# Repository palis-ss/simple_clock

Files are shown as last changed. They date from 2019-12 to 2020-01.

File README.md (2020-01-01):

# simple_clock

## Description
This repository contains the firmware for a replacement clock that I put into an old chassis.  The old clock was an analog clock.  I rebuilt a new one as a digital clock using 7-segment LEDs.  It uses the Blue Pill board ([Link](https://stm32-base.org/boards/STM32F103C8T6-Blue-Pill)) as its processor and relies on the RTC module of the STM32.  I removed the battery and replaced with a DC jack.  I also added a backup battery for the RTC.

The replacement clock must fit in the old chassis, so I made a bracket with 3D printing.  The mainboard that holds the Blue Pill and the 7-segments was designed in Eagle, which the schematics and gerber files are included in this repo.

For the firmware, the project was created using STM32CubeMX which uses STM32 HAL as the library.  The code is actually simple but I made it look harder than it actually is.  The big chunk of code is how I handle buttons.  The part about time keeping is not so much as the RTC on this MCU is very easy to use.  Nonetheless, there are a number of problems with the HAL library.  I'm listing the ones that affected this project here.
- The RTC's `HAL_RTC_GetTime` must be followed by the `HAL_RTC_GetDate` in order for it to work properly.
- The initialization routine `MX_RTC_Init`, by default, intializes the RTC's time to 0.  This part must be removed manually in order to use backup time from RTC.
- The default IRQ handler for Systick Interrupt is not called in the interrupt routine.  You must add it manually.  This part is a minor problem and not relevant to this project but I use it so I decided to mention here anyway.

## Notes on Board Assembling
- Make sure to take care of vias first if you develop the board yourself.
- Then do the MAX7219 next as it needs to be soldered on both sides.
- The rest of components can be soldered anytime afterwards.

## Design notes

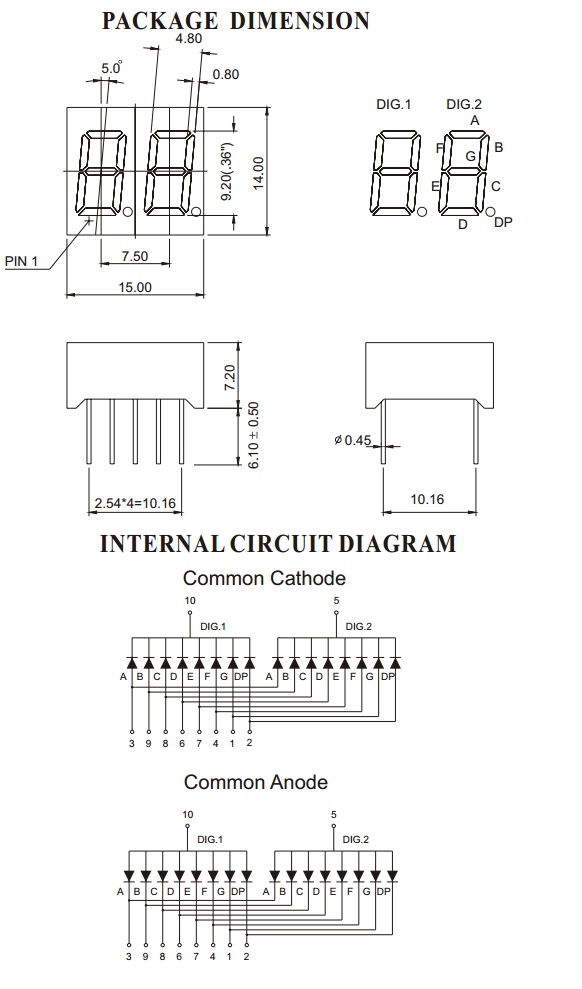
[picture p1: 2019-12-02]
ref/8z.jpg

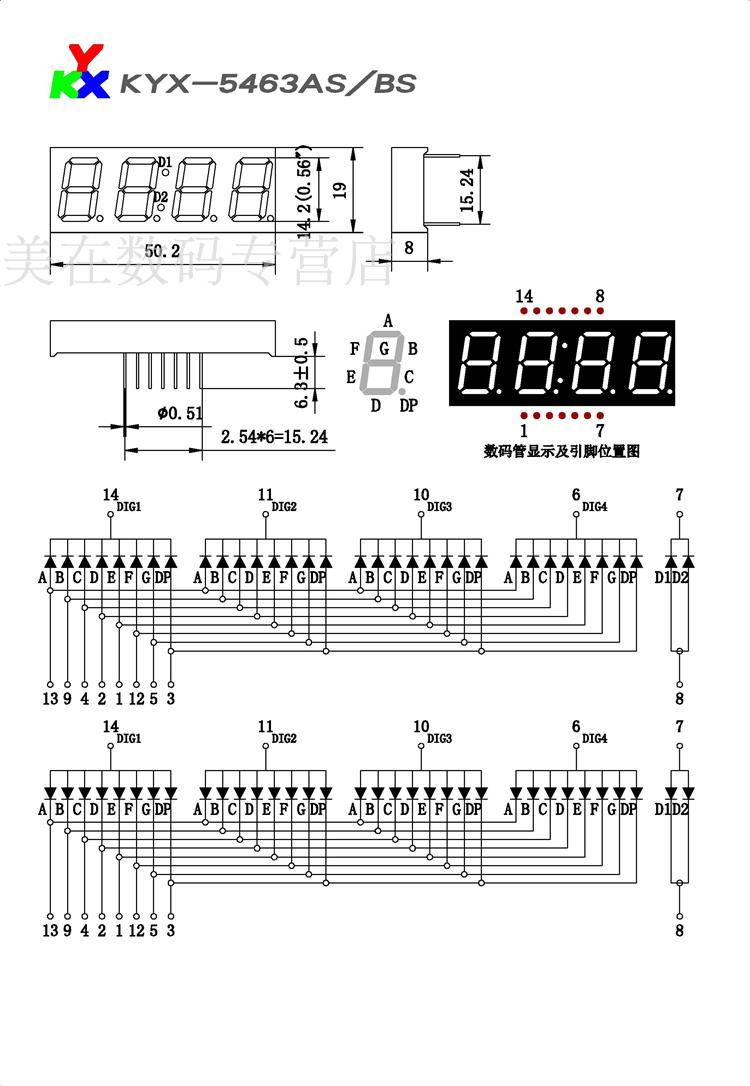
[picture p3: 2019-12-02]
ref/yp.jpg

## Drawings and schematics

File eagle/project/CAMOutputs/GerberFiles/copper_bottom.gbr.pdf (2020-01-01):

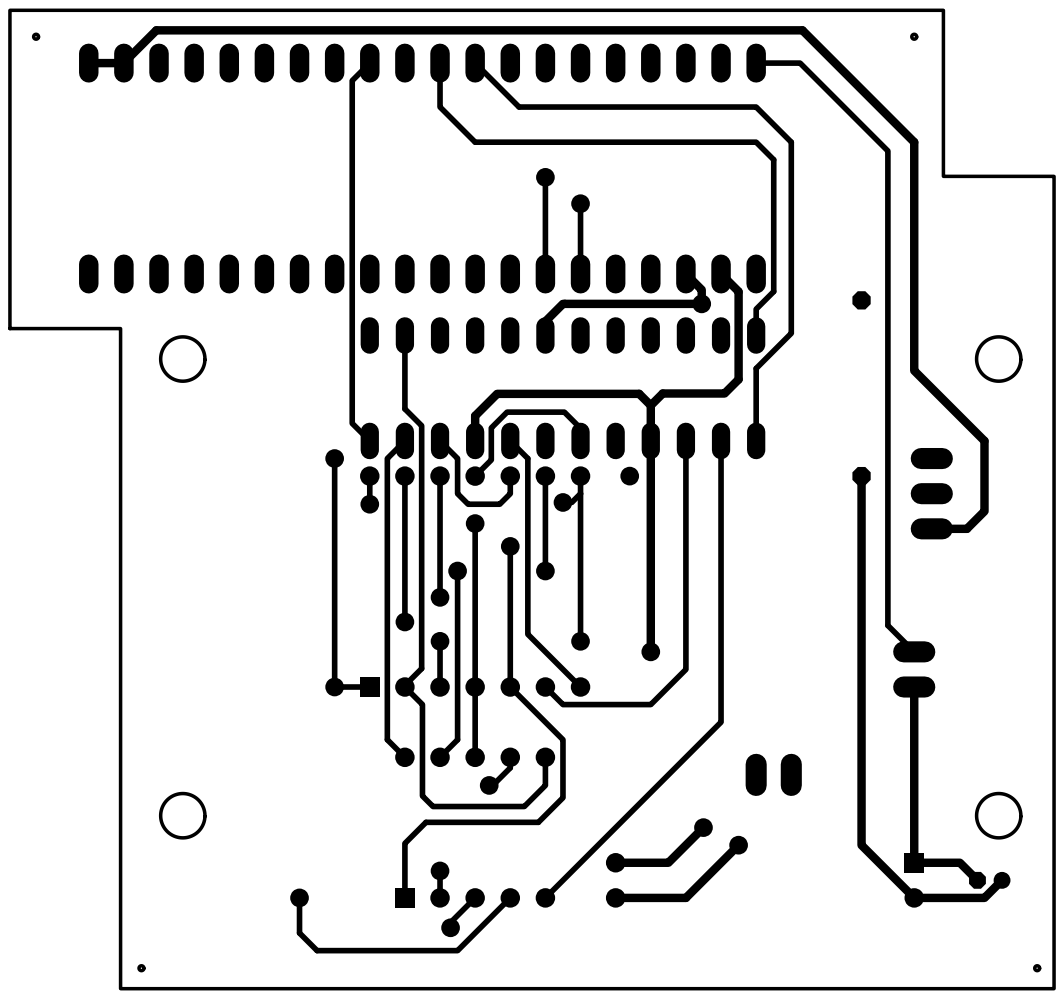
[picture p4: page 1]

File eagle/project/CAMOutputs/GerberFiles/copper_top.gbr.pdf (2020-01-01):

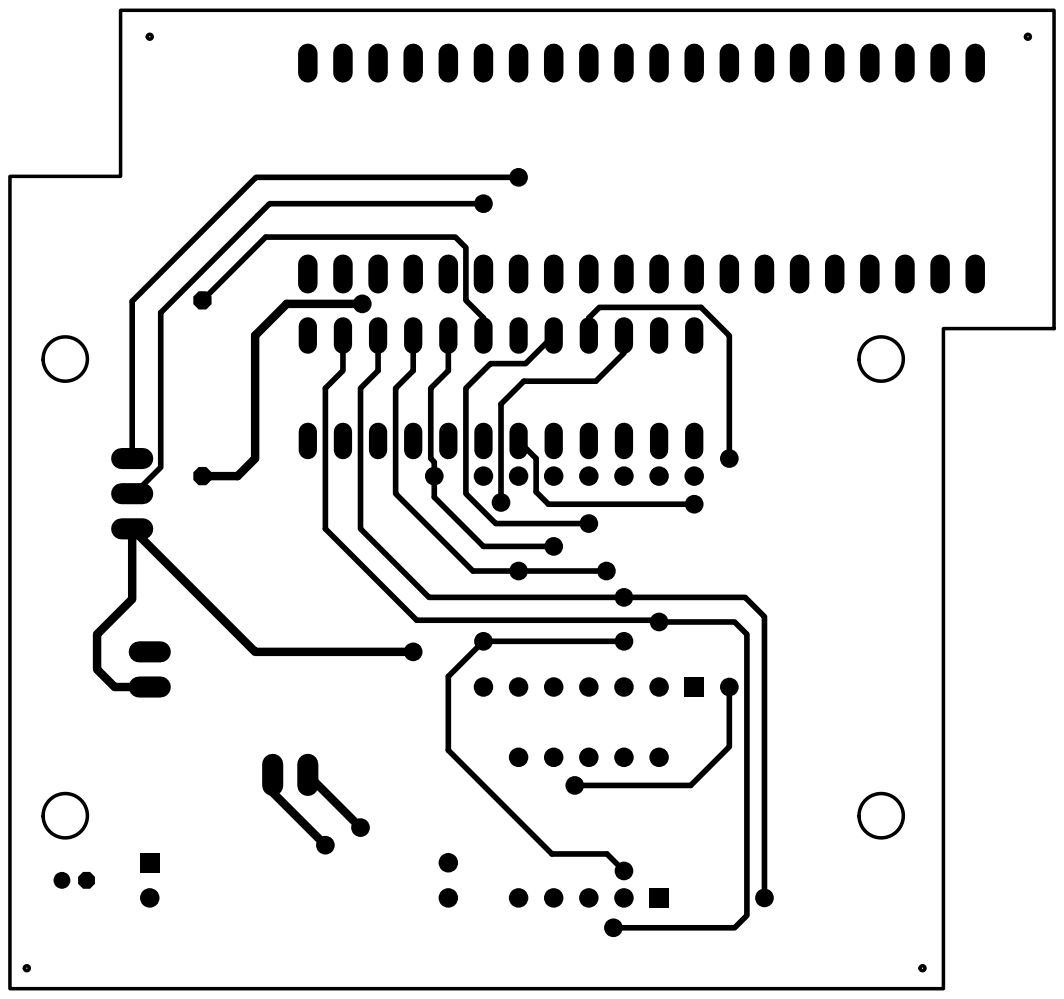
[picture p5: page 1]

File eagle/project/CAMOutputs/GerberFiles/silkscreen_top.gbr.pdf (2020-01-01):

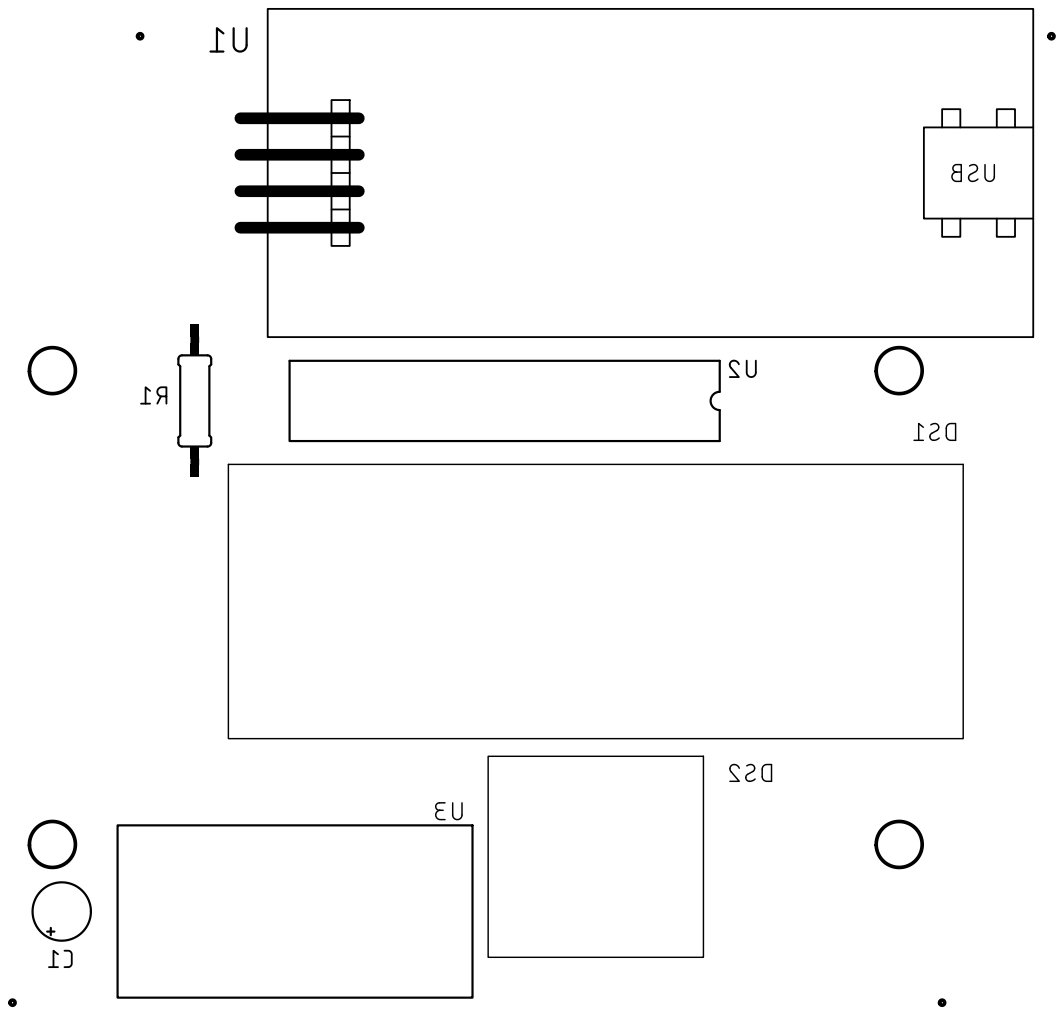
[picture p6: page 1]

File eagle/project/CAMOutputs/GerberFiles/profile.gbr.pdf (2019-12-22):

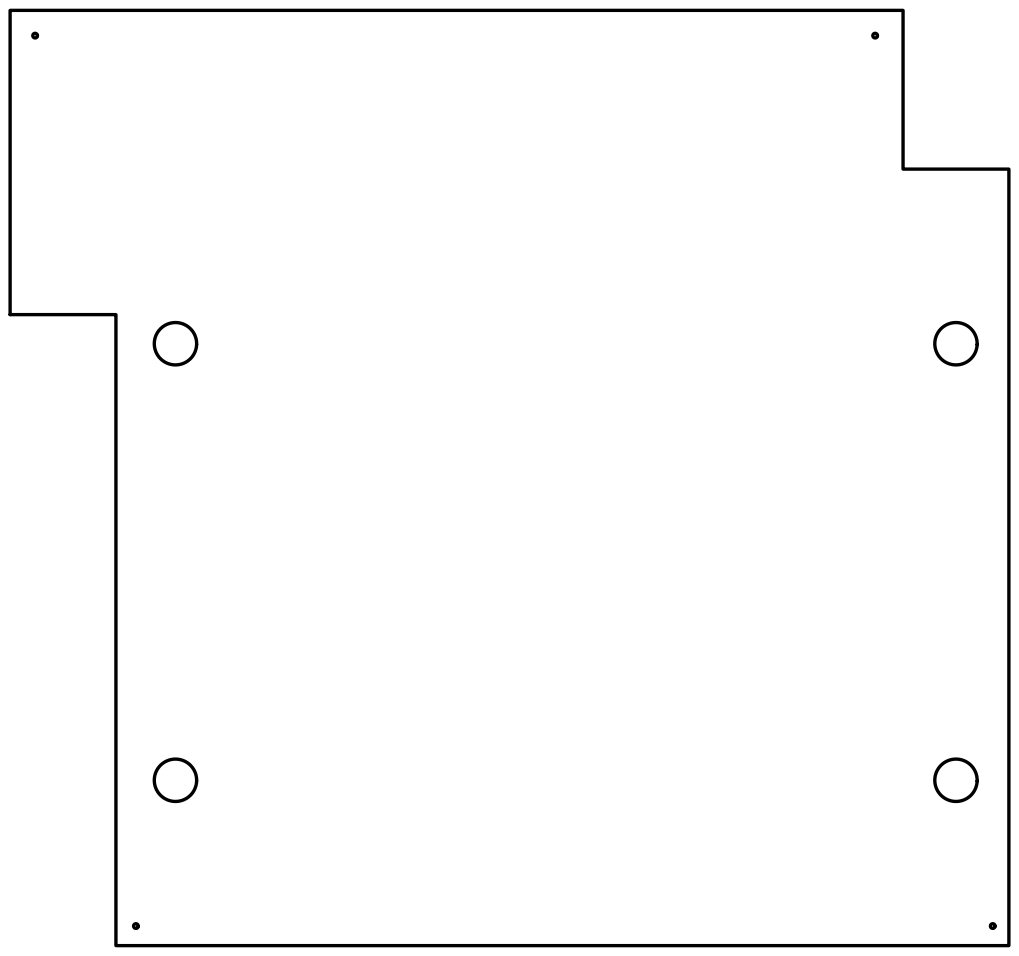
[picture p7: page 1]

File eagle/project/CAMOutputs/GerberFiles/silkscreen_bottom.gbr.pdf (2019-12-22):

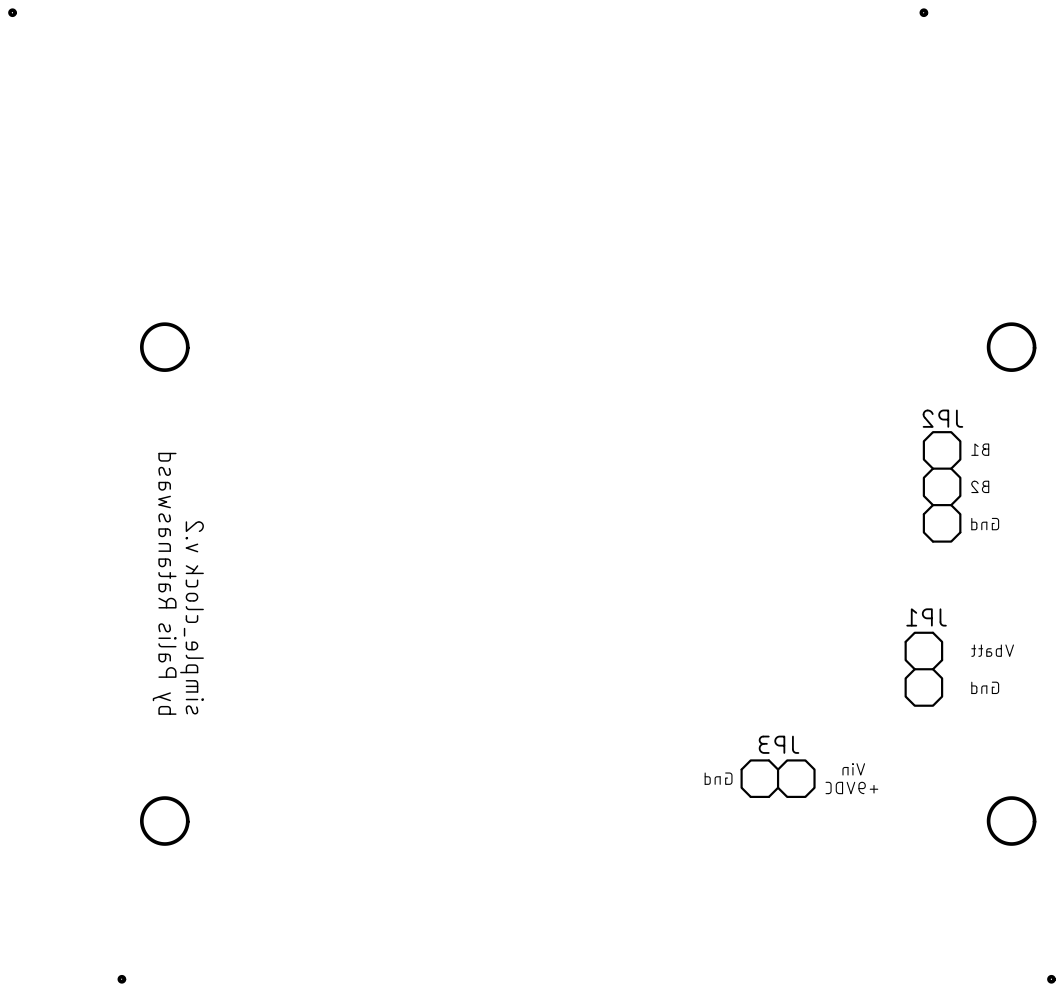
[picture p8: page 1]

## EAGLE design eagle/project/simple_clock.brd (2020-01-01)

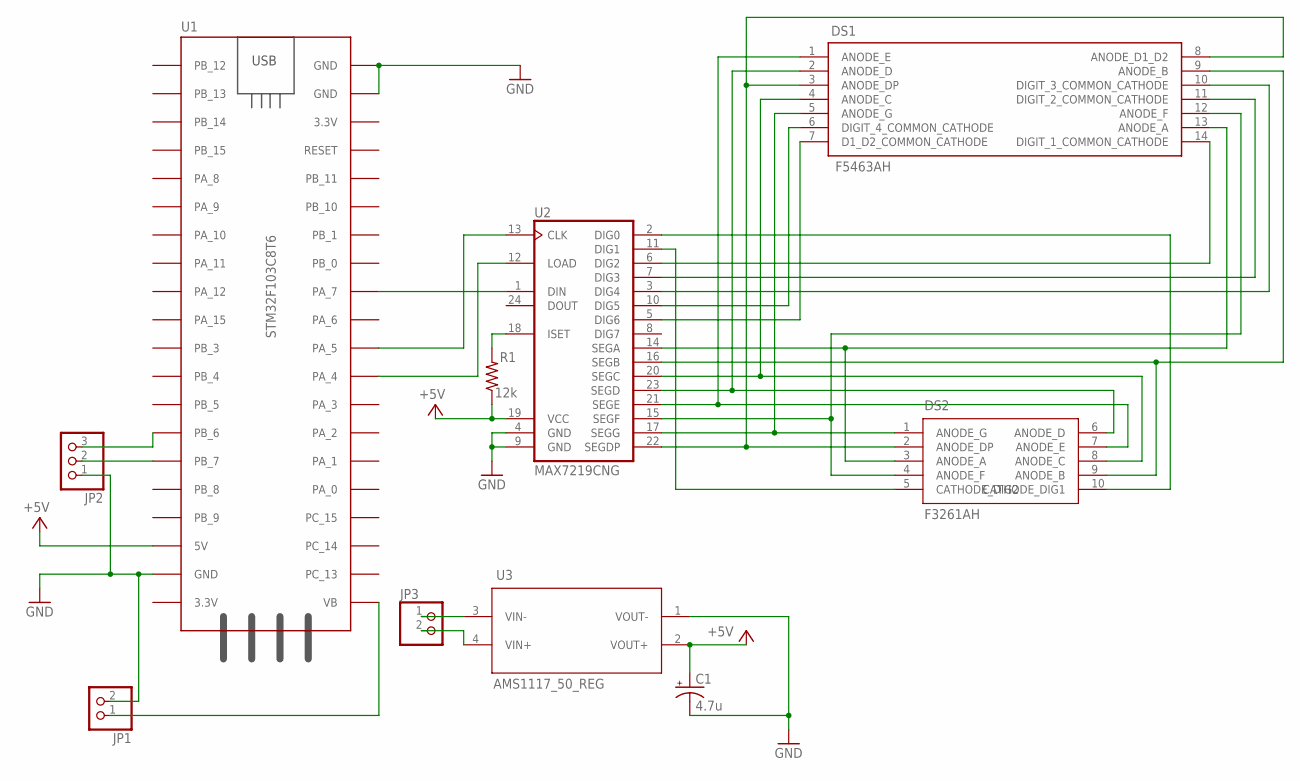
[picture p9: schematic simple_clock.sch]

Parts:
C1: 4.7u; E1,8-4
DS1: F5463AH
DS2: F3261AH
JP1, JP3: PINHD-1X2; 1X02
JP2: PINHD-1X3; 1X03
R1: 12k; 0207/12
U1: STM32F103C8T6
U2: MAX7219CNG; DIL24-3
U3: AMS1117_50_REG

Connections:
+5V: C1.+, R1.1, U1.5V, U2.19 (VCC), U3.2 (VOUT+)
GND: C1.-, JP1.2, JP2.1, U1.GND_1 (GND), U1.GND_2 (GND), U1.GND_3 (GND), U2.4 (GND), U2.9 (GND), U3.1 (VOUT-)
unnamed: DS1.10 (DIGIT_3_COMMON_CATHODE), U2.3 (DIG4)
unnamed: DS1.7 (D1_D2_COMMON_CATHODE), U2.5 (DIG6)
unnamed: U1.PA_7, U2.1 (DIN)
unnamed: DS1.14 (DIGIT_1_COMMON_CATHODE), U2.6 (DIG2)
unnamed: DS2.10 (CATHODE_DIG1), U2.2 (DIG0)
unnamed: DS2.5 (CATHODE_DIG2), U2.11 (DIG1)
unnamed: DS1.11 (DIGIT_2_COMMON_CATHODE), U2.7 (DIG3)
unnamed: DS1.6 (DIGIT_4_COMMON_CATHODE), U2.10 (DIG5)
unnamed: U1.PA_5, U2.13 (CLK)
unnamed: U1.PA_4, U2.12 (LOAD)
unnamed: DS1.13 (ANODE_A), DS2.3 (ANODE_A), U2.14 (SEGA)
unnamed: DS1.1 (ANODE_E), DS2.7 (ANODE_E), U2.21 (SEGE)
unnamed: DS1.12 (ANODE_F), DS2.4 (ANODE_F), U2.15 (SEGF)
unnamed: DS1.4 (ANODE_C), DS2.8 (ANODE_C), U2.20 (SEGC)
unnamed: DS1.2 (ANODE_D), DS2.6 (ANODE_D), U2.23 (SEGD)
unnamed: DS1.3 (ANODE_DP), DS1.8 (ANODE_D1_D2), DS2.2 (ANODE_DP), U2.22 (SEGDP)
unnamed: DS1.5 (ANODE_G), DS2.1 (ANODE_G), U2.17 (SEGG)
unnamed: R1.2, U2.18 (ISET)
unnamed: JP1.1, U1.VB
unnamed: JP2.2, U1.PB_7
unnamed: JP2.3, U1.PB_6
unnamed: JP3.1, U3.3 (VIN-)
unnamed: JP3.2, U3.4 (VIN+)
unnamed: DS1.9 (ANODE_B), DS2.9 (ANODE_B), U2.16 (SEGB)

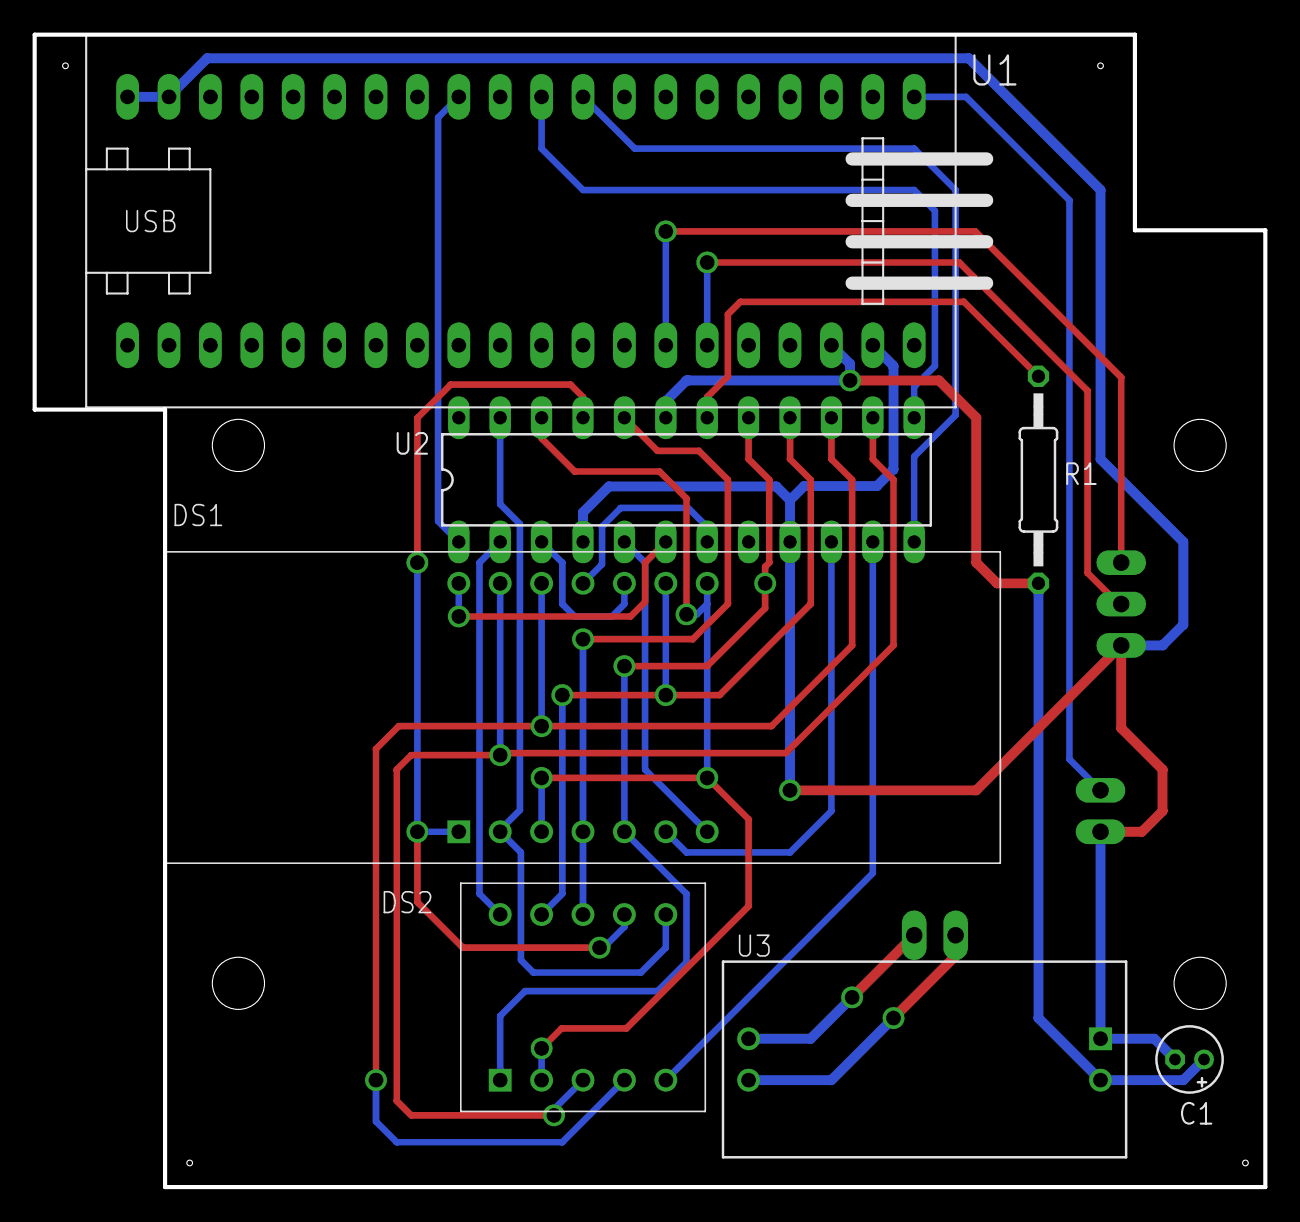
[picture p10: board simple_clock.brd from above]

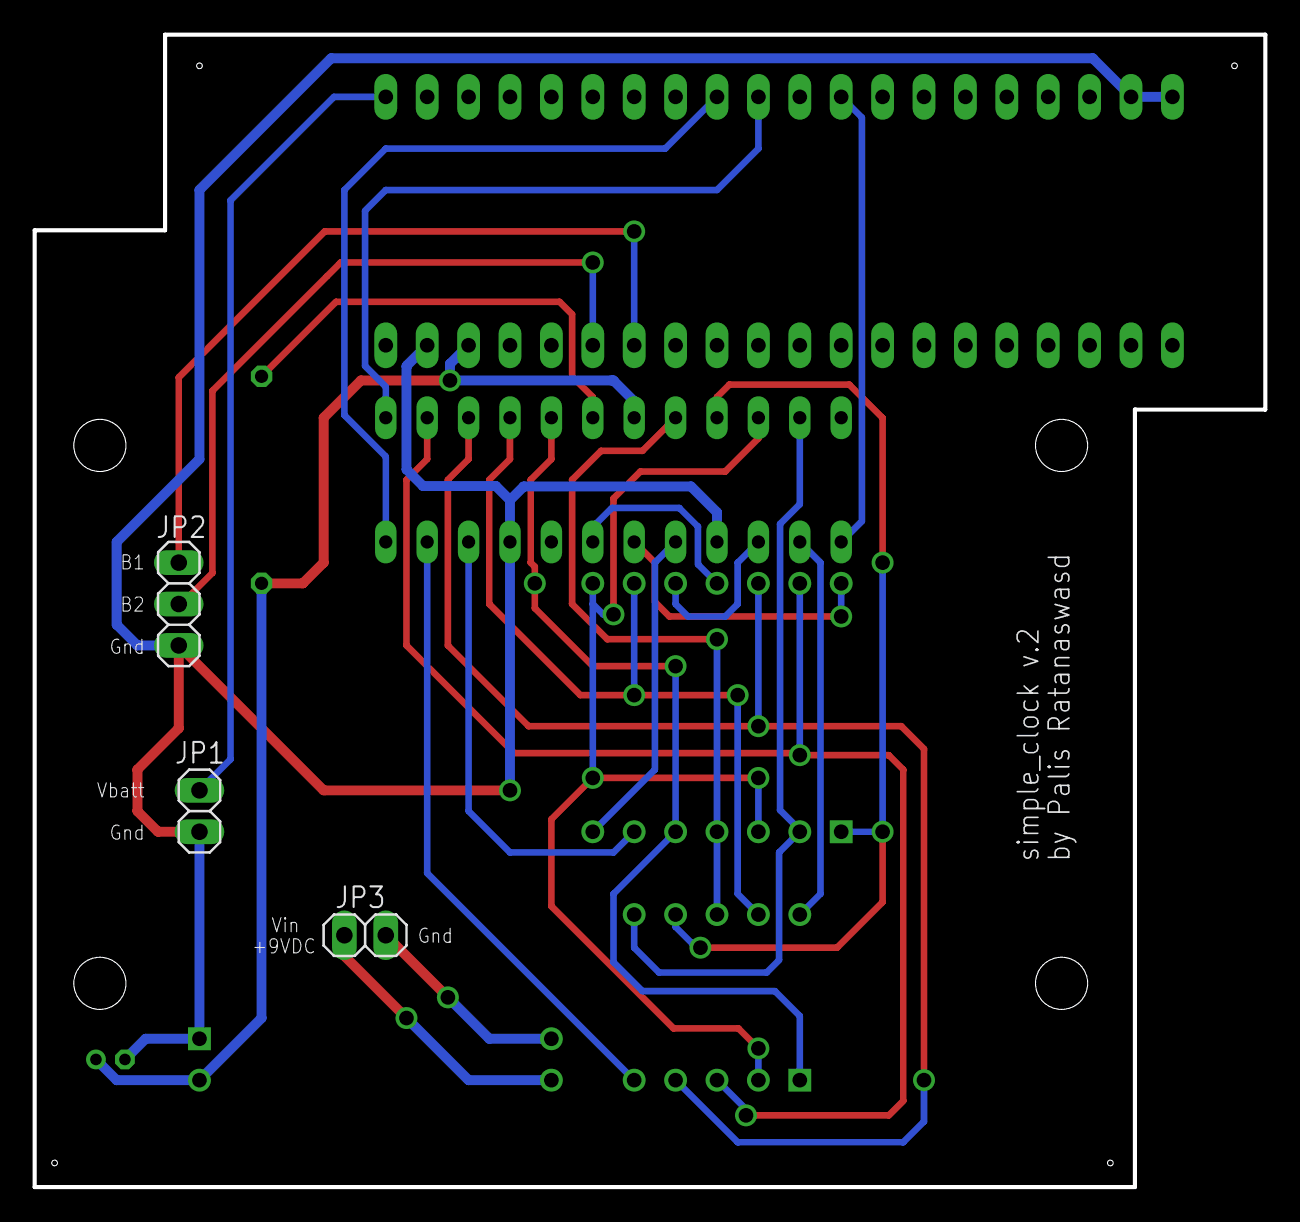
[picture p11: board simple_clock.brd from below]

Board: 2 copper layers, 75.5 x 70.7 mm, 10 parts (3 on the bottom side), 26 nets.

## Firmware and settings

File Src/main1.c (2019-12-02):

/**
  ******************************************************************************
  * @file           : main.c
  * @brief          : Main program body
  ******************************************************************************
  * This notice applies to any and all portions of this file
  * that are not between comment pairs USER CODE BEGIN and
  * USER CODE END. Other portions of this file, whether 
  * inserted by the user or by software development tools
  * are owned by their respective copyright owners.
  *
  * Copyright (c) 2018 STMicroelectronics International N.V. 
  * All rights reserved.
  *
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
  ******************************************************************************
  */
/* Includes ------------------------------------------------------------------*/
#include "main.h"
#include "stm32f1xx_hal.h"
#include "usb_device.h"

/* USER CODE BEGIN Includes */
#include "usbd_cdc_if.h"
#include <stdio.h>
#include <string.h>

#include "SevenSegment.h"

#define NUM_BUTTONS 4
/* USER CODE END Includes */

RTC_HandleTypeDef hrtc;

SPI_HandleTypeDef hspi1;

/* USER CODE BEGIN PV */
RTC_TimeTypeDef sTime1 = {0};

uint16_t keypressed[NUM_BUTTONS] = {0}, keydown[NUM_BUTTONS] = {0};
uint32_t kdtick[NUM_BUTTONS] = {0}, lasttick = 0;
/* USER CODE END PV */

void SystemClock_Config(void);
static void MX_GPIO_Init(void);
static void MX_SPI1_Init(void);
static void MX_RTC_Init(void);

/* USER CODE BEGIN PFP */

/* USER CODE END PFP */

/* USER CODE BEGIN 0 */
void DisplayTime(RTC_TimeTypeDef t)
{
	SevenSegment_SetDigit(1, t.Seconds%10);							
	SevenSegment_SetDigit(0, t.Seconds/10);
	SevenSegment_SetDigit(5, t.Minutes%10);
	SevenSegment_SetDigit(4, t.Minutes/10);
	SevenSegment_SetDigit(3, t.Hours%10);
	if(t.Hours>=10)
		SevenSegment_SetDigit(2, t.Hours/10);	
	else
		SevenSegment_SetDigit(2, 15);
}

void UpdateTime(uint8_t digittoset)
{
	uint8_t num0 = 0;
	
		switch(digittoset)
		{
			case 1:
				num0 = sTime1.Hours%10;
				
				if(num0 == 9)
					sTime1.Hours-=9;
				else
					sTime1.Hours++;			
				break;
			case 2:
				num0 = sTime1.Hours/10;
			
				if(num0 == 2)
					sTime1.Hours-=20;
				else
					sTime1.Hours+=10;
				
				while(sTime1.Hours > 24)
					sTime1.Hours-=10;
				
				break;						
			case 3:
				num0 = sTime1.Minutes%10;
				
				if(num0 == 9)
					sTime1.Minutes-=9;
				else
					sTime1.Minutes++;						
				break;
			case 4:
				num0 = sTime1.Minutes/10;
			
				if(num0 == 5)
					sTime1.Minutes-=50;
				else
					sTime1.Minutes+=10;
				break;
			case 5:  // seconds
				sTime1.Seconds = 0;
				break;
		}
}
/* USER CODE END 0 */

/**
  * @brief  The application entry point.
  *
  * @retval None
  */
int main(void)
{
  /* USER CODE BEGIN 1 */
	char s[20];
	uint32_t nowtick, updatetick = 0;
	uint8_t digittoset = 0;
	RTC_TimeTypeDef newtime;
	//RTC_DateTypeDef sDate1;
	
  /* USER CODE END 1 */

  /* MCU Configuration----------------------------------------------------------*/

  /* Reset of all peripherals, Initializes the Flash interface and the Systick. */
  HAL_Init();

  /* Configure the system clock */
  SystemClock_Config();

  /* Initialize all configured peripherals */
  MX_GPIO_Init();
  MX_SPI1_Init();
  MX_USB_DEVICE_Init();
  MX_RTC_Init();
  /* USER CODE BEGIN 2 */
	
	SevenSegment_Init(8, SPI1_CS_GPIO_Port, SPI1_CS_Pin, 3, &hspi1);	
	
	HAL_Delay(100);
	SevenSegment_SetPeriod(6, 1);
  /* USER CODE END 2 */

  /* Infinite loop */
  /* USER CODE BEGIN WHILE */
  while (1)
  {

  /* USER CODE END WHILE */

  /* USER CODE BEGIN 3 */
		
		nowtick = HAL_GetTick();
		
		// check if our desired key is pressed
		
		if(keypressed[0] >0)  // check bit mask		
		{
			keypressed[0] = 0;
			keydown[0] = 0;			
			
			// set time
			if(digittoset > 0)
			{				
				UpdateTime(digittoset);
				DisplayTime(sTime1);		
			}

			continue;
		}
		
		
		
		
		if(keypressed[1] >0)  // check bit mask		
		{
			keypressed[1] = 0;
			keydown[1] = 0;			
			
			digittoset++;
			if(digittoset > 5)
				digittoset = 0;
			else
				SevenSegment_SetPeriod(6, 1);
			
				switch(digittoset)
				{
				case 1:  // hour unit
					HAL_RTC_GetTime(&hrtc, &sTime1, RTC_FORMAT_BIN);
				
					SevenSegment_SetPeriod(3, 1);					
					break;
				case 2:  // hour tenth
					SevenSegment_SetPeriod(3, 0);				
					SevenSegment_SetPeriod(2, 1);					
					break;
				case 3:  // minute unit
					SevenSegment_SetPeriod(2, 0);
					SevenSegment_SetPeriod(5, 1);
					break;
				case 4:  // minute tenth					
					SevenSegment_SetPeriod(5, 0);
					SevenSegment_SetPeriod(4, 1);
					break;				
				case 5:  // seconds					
					SevenSegment_SetPeriod(4, 0);
					SevenSegment_SetPeriod(1, 1);
					break;				
				case 0:				
					SevenSegment_SetPeriod(1, 0);
				
					HAL_RTC_SetTime(&hrtc, &sTime1, RTC_FORMAT_BIN);
					break;
				
			}

			continue;
		}		

		if(keydown[0] >0)  // check bit mask
		{
				if(digittoset > 0 && (kdtick[0] > 0) && (nowtick - kdtick[0] > 1000))
				{
					// going through fast mode
					while(keydown[0])
					{
						UpdateTime(digittoset);						
						DisplayTime(sTime1);							
						HAL_Delay(200);
					}
				}				
				continue;
		}
			
		// display time
		if(digittoset == 0)
		{
			HAL_RTC_GetTime(&hrtc, &newtime, RTC_FORMAT_BIN);
			
			if(newtime.Hours != sTime1.Hours || newtime.Minutes!=sTime1.Minutes || newtime.Seconds!=sTime1.Seconds)
			{
				sTime1 = newtime;
				
				DisplayTime(sTime1);
		
				updatetick = nowtick;
				SevenSegment_SetPeriod(6, 1);
				
				//sprintf(s, "%d:%d:%d\r\n", sTime1.Hours, sTime1.Minutes, sTime1.Seconds);				
				//CDC_Transmit_FS(s, strlen(s));
			}
			
			if(nowtick - updatetick >= 500)
					SevenSegment_SetPeriod(6, 0);
		}
				
	}
  /* USER CODE END 3 */

}

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
/* USER CODE BEGIN 4 */
void HAL_SYSTICK_Callback(void)
{
	if((HAL_GetTick()%1000) == 0)
		HAL_GPIO_TogglePin(LD1_GPIO_Port, LD1_Pin);
}

void HAL_GPIO_EXTI_Callback(uint16_t GPIO_Pin)
{
	uint32_t nowtick = 0;		
	uint8_t pinno;
	
	switch(GPIO_Pin)
	{
		case BTN1_Pin:
			pinno = 0;
			break;
		case BTN2_Pin:
			pinno = 1;
			break;
		case BTN3_Pin:
			pinno = 2;
			break;
		case BTN4_Pin:
			pinno = 3;
			break;
		default:
			return;
	}
	
	nowtick = HAL_GetTick();
	
	if(kdtick[pinno] > 0)
	{
		if(nowtick - kdtick[pinno] > 80)  // key supposedly up
		{
				kdtick[pinno] = 0;
				keypressed[pinno] = 1;
				keydown[pinno] = 0;
		}
	}
	else
	{
		if(nowtick - lasttick > 80)
		{			
				keydown[pinno] = 1;
				kdtick[pinno] = nowtick; 	// key first down
		}
	}
	lasttick = nowtick;

}
/* USER CODE END 4 */
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


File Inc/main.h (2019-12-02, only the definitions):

#define LD0_Pin GPIO_PIN_13
#define LD0_GPIO_Port GPIOC
#define SPI1_CS_Pin GPIO_PIN_4
#define SPI1_CS_GPIO_Port GPIOA
#define BTN1_Pin GPIO_PIN_6
#define BTN1_GPIO_Port GPIOB
#define BTN1_EXTI_IRQn EXTI9_5_IRQn
#define BTN2_Pin GPIO_PIN_7
#define BTN2_GPIO_Port GPIOB
#define BTN2_EXTI_IRQn EXTI9_5_IRQn
#define BTN3_Pin GPIO_PIN_8
#define BTN3_GPIO_Port GPIOB
#define BTN3_EXTI_IRQn EXTI9_5_IRQn
#define BTN4_Pin GPIO_PIN_9
#define BTN4_GPIO_Port GPIOB
#define BTN4_EXTI_IRQn EXTI9_5_IRQn

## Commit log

2019-12-03 added eagle files
    [footprint_calc.xlsx, simple_clock.sch]
2019-12-03 added component
    [footprint_calc.xlsx, simple_clock.brd]
2019-12-10 made pcb in Eagle
    [footprint_calc.xlsx, simple_clock.brd, simple_clock.sch]
2019-12-12 created Gerber files
    [simple_clock.brd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]
2019-12-15 ready to make pcb
    [simple_clock.brd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]
2019-12-20 updated board design
    [simple_clock.brd, simple_clock.sch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]
2019-12-22 updated footprints
    [simple_clock.brd, simple_clock.sch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]
2019-12-29 revised pcb
    [simple_clock_old.brd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]
2020-01-01 updated firmware
    [simple_clock.brd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]
2020-05-10 converted project into STM32CubeIDE

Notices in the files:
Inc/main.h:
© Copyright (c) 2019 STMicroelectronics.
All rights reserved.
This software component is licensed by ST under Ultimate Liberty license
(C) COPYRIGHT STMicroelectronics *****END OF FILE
